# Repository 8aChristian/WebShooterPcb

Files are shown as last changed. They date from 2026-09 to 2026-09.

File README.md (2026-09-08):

# 🕸️ WebShooter — Wearable Actuation & High-Response Sensing PCB

<div align="center">



[]()
[]()


</div>

<p align="center">
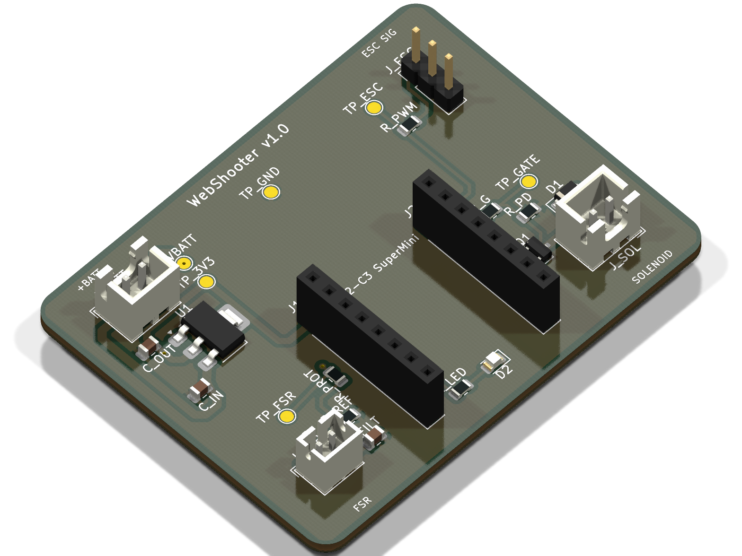
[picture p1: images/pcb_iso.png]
WebShooter 3D PCB Render Isometric View
  
</p>

---

## 1. 🎯 Objective

**WebShooter** is a compact, high-reliability wearable controller PCB designed for rapid biosignal/force acquisition, low-latency electronic valve actuation, and external brushless motor ESC control.

Built around the **ESP32-C3 SuperMini** (RISC-V 32-bit architecture), the system is engineered to withstand intense inductive transients and severe electromagnetic interference (EMI) from high-power loads while providing precision analog readings from a Force Sensing Resistor (FSR).

> [!NOTE]
> **Key Capabilities:**
> - **Fast Response Time:** Sub-millisecond analog force detection via hardware RC filtering.
> - **Inductive Load Immunity:** High-speed Schottky flyback suppression and isolated ground return loops.
> - **Modular Design:** Socketed MCU mounting for effortless replacement and maintenance.

---

## 2. 🏗️ System Architecture

```mermaid
graph LR
    subgraph Power_Stage ["Power and Regulation Stage"]
        BATT["Battery LiPo 2S (7.4V - 8.4V)"] -->|J_BATT| LDO["AMS1117-3.3 LDO"]
        LDO -->|"10uF In + 22uF Out"| V33["3.3V DC Clean Rail"]
    end

    subgraph MCU_Stage ["Control Unit ESP32-C3 SuperMini"]
        V33 --> MCU["ESP32-C3 (RISC-V @ 160MHz)"]
        MCU -->|GPIO8| LED["Status Indicator LED"]
    end

    subgraph Sensor_Stage ["Analog Force Sensing"]
        V33 --> FSR_DIV["10k Ohm Reference Divider"]
        FSR["FSR402 Sensor"] --> FSR_DIV
        FSR_DIV -->|"100nF LowPass + 1k Ohm Prot"| ADC["GPIO0 (ADC1_CH0)"]
    end

    subgraph Actuation_Stage ["Power Actuation and Motor Drive"]
        MCU -->|GPIO7 Logic Gate| DRV["AO3400A N-MOSFET (30V / 5.7A)"]
        BATT -->|7.4V Heavy Rail| SOL["Solenoid Valve (Inductive Load)"]
        DRV -->|"Drain + SS14 Flyback Diode"| SOL
        MCU -->|"GPIO6 PWM - 100 Ohm Damper"| ESC["External ESC (SpeedX2 1404 BLDC)"]
        BATT -.->|"Direct Battery Wiring"| ESC
    end
```

- **MCU:** ESP32-C3 SuperMini (RISC-V 32-bit single-core @ 160 MHz, 400 KB SRAM, 4 MB Flash, Wi-Fi + BLE 5).
- **Analog Front-End (AFE):** Precision voltage divider with a 100 nF ceramic low-pass filter ($f_c \approx 159\text{ Hz}$) and $1\text{ k}\Omega$ series current limiter.
- **Power Management & Drive:** AMS1117-3.3 LDO regulator with dual ceramic filtering; logic-level AO3400A N-MOSFET with SS14 Schottky flyback protection; isolated ESC PWM signaling.

---

## 3. 🔬 Component Selection & Design Decisions

| Subsystem | Component Selected | Engineering Rationale & Justification |
| :--- | :--- | :--- |
| **Microcontroller** | **ESP32-C3 SuperMini** | Ultra-compact footprint ($22.5 \times 18\text{ mm}$), native 12-bit ADC, hardware PWM timers, low power consumption, and integrated 2.4 GHz Wi-Fi/BLE for wireless telemetry. Mounted on **2.54 mm female headers** (`J1`, `J2`) to prevent module thermal stress during assembly and allow instant replacement. |
| **Solenoid Driver** | **AO3400A N-MOSFET** (SOT-23) | Ultra-low on-resistance ($R_{DS(on)} < 33\text{ m}\Omega$ @ $V_{GS} = 2.5\text{V}$), fully saturated with the ESP32's 3.3V logic. At $I = 0.8\text{A}$, power dissipation is negligible ($P_{cond} \approx 21.1\text{ mW}$), eliminating the need for bulky heatsinks. |
| **Flyback Protection** | **SS14 Schottky Diode** (SOD-123) | Placed directly in antiparallel across the solenoid terminals. Ultrafast reverse recovery ($t_{rr} < 10\text{ ns}$) and $0.5\text{V}$ forward drop clamp inductive voltage spikes ($V = -L \frac{di}{dt}$) to protect the MOSFET drain and ground plane from EMI bursts. |
| **Voltage Regulator** | **AMS1117-3.3** (SOT-223) | Handles 7.4V–8.4V LiPo 2S input with 1A current capacity. SOT-223 tab is tied to the output plane for optimal thermal dissipation. Paired with $10\,\mu\text{F}$ input and $22\,\mu\text{F}$ output ceramic X7R capacitors. |
| **Force Sensor AFE** | **FSR402 Divider + RC Filter** | Converts pressure ($0.2\text{ N} - 20\text{ N}$) into a clean $0.03\text{V} - 3.0\text{V}$ voltage curve. The hardware RC filter ($10\text{ k}\Omega \parallel 100\text{ nF}$) removes mechanical contact bounce and EMI from nearby motor switching. |
| **Motor & ESC Isolation** | **Signal-Only PWM Interface** | Heavy motor currents (up to 15A from the SpeedX2 1404 BLDC) are powered **directly from the battery pack wiring harness**. Only the PWM control line and reference ground pass through the PCB, preventing ground bounce and motor hash from corrupting the ADC. |

---

## 4. 📐 Schematic Overview

<div align="center">
  <a href="schematic/WebShooter_Schematic.pdf">
    WebShooter Complete Schematic Diagram
  </a>
  <p><em>Full vector PDF schematic is available in the <a href="schematic/WebShooter_Schematic.pdf"><code>/schematic</code></a> folder.</em></p>
</div>

> [!TIP]
> **Complete Schematic Documentation:**
> - 📄 **PDF Format:** [`schematic/WebShooter_Schematic.pdf`](schematic/WebShooter_Schematic.pdf)
> - 🎨 **Vector SVG:** [`schematic/WebShooter_Schematic.svg/`](schematic/WebShooter_Schematic.svg/)
> - 💻 **KiCad Source:** [`pcb/WebShooter.kicad_sch`](pcb/WebShooter.kicad_sch)

---

## 5. 🖨️ PCB Layout & Routing Strategy

<div align="center">

| Top Layer 2D Layout (F.Cu) | Bottom Layer 2D Layout (B.Cu) |
| :---: | :---: |
| Top Layer 2D PCB Layout | Bottom Layer 2D PCB Layout |

| 3D Render - Top Side | 3D Render - Bottom Side |
| :---: | :---: |
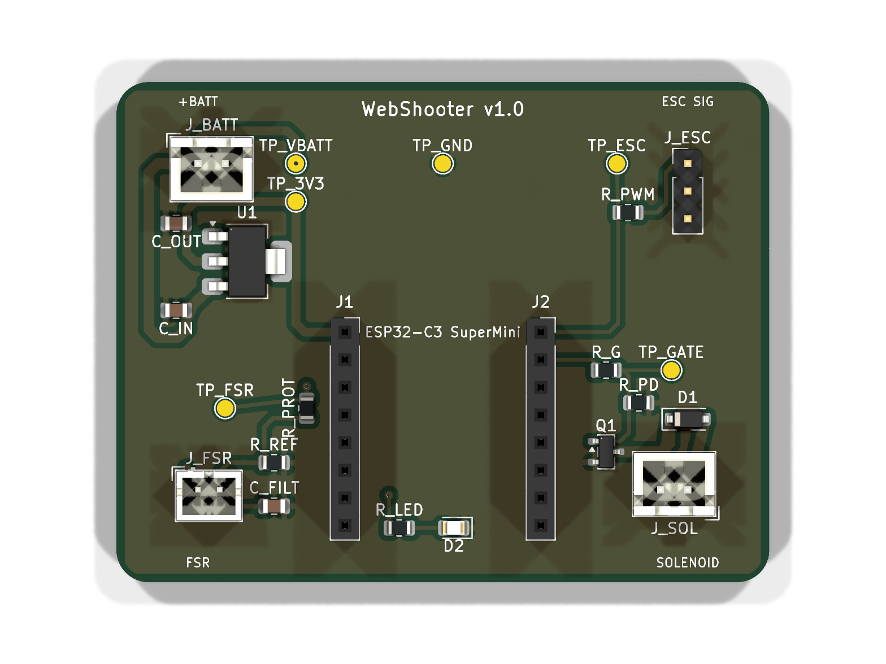
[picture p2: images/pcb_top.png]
Top Side 3D PCB Render
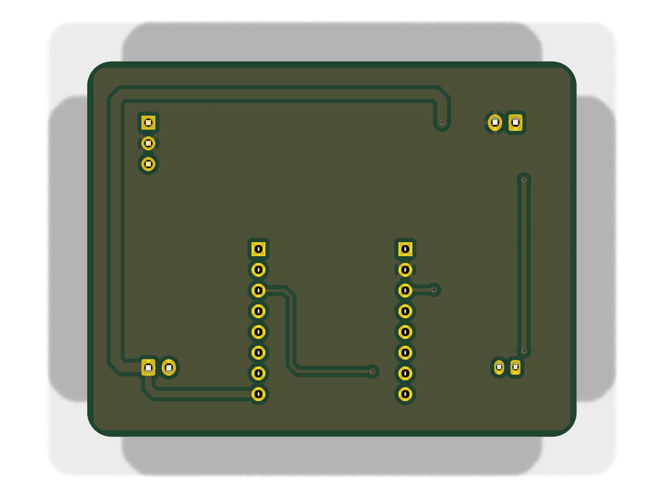
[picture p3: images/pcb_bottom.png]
Bottom Side 3D PCB Render
|  |  |

</div>

### 🛠️ Layer Stackup & Dimensions
- **Layer Count:** 2-Layer FR4 ($1.6\text{ mm}$ board thickness, $1\text{ oz} / 35\,\mu\text{m}$ copper weight).
- **Board Dimensions:** $38.0\text{ mm} \times 38.0\text{ mm}$ with $2.0\text{ mm}$ corner radius fillets (Ultra-compact wearable standard).
- **Mounting Hole Grid:** 4x M2 mounting holes on a $31.0 \times 31.0\text{ mm}$ pattern ($3.5\text{ mm}$ from board edges).

### 📐 Routing Guidelines & DFM Standards Applied
1. **Strict 45° Mitered Routing (Zero 90° Corners):**
   - All track bends utilize **45-degree chamfers** or smooth radii.
   - *Why:* Eliminates **acid traps** during chemical etching in fab, avoids acute impedance steps, and prevents solder mask delamination.
2. **Edge Pullback Clearance ($\ge 1.0\text{ mm}$):**
   - All copper tracks, vias, and copper pour zones maintain at least **$1.0\text{ mm}$ of clearance** from the `Edge_Cuts` perimeter.
   - *Why:* Prevents copper shearing, burrs, and shorts during CNC V-scoring and board routing.
3. **Trace Width Dimensioning (IPC-2152):**
   - **Power & Solenoid Traces:** $1.0\text{ mm} - 1.2\text{ mm}$ (Handles up to $3\text{A}$ continuous with $\Delta T < 10^\circ\text{C}$).
   - **3.3V Power Distribution:** $0.8\text{ mm}$.
   - **Digital PWM & Analog Signals:** $0.35\text{ mm} - 0.40\text{ mm}$.
4. **Dual Continuous Ground Planes:**
   - Both `F.Cu` and `B.Cu` feature unbroken GND copper zones connected through thermal reliefs (`ZONE_CONNECTION_THERMAL`) on all through-hole and SMD ground pins.

---

## 6. ✅ DRC & Quality Verification

Automated Design Rule Check (DRC) executed via `kicad-cli`:

```text
** KiCad 10 Design Rule Check Report **
Project: WebShooter.kicad_pcb
Date: 2026-08-20

[+] Status: PASSED
[+] Total DRC Violations: 0
[+] Unconnected Elements: 0
[+] Footprint Courtyard Overlaps: 0
[+] Solder Mask Bridges: 0
[+] Silk Over Exposure: 0
```

> [!IMPORTANT]
> The full verification report is saved in [`pcb/WebShooter-drc.rpt`](pcb/WebShooter-drc.rpt).

---

## 7. 🧊 3D Model & Mechanical Integration

<p align="center">
  3D Raytracing Render of WebShooter PCB
</p>

- **PCB 3D Model:** Ready-to-import STEP file:
  - 📁 [`3d-model/WebShooter.step`](3d-model/WebShooter.step)
- **Wearable Case / Enclosure (CAD):** Parametric wrist case model for 3D printing:
  - 📦 [`3d-model/WEBSHOOTERCASEFINAL.f3d`](3d-model/WEBSHOOTERCASEFINAL.f3d) (Autodesk Fusion 360 source archive)
- **Mechanical Mounting:** 4x M2 mounting holes on a $31.0 \times 31.0\text{ mm}$ square grid ($3.5\text{ mm}$ edge offset), designed to mate directly with the 3D-printed enclosure standoffs.

---

## 8. 🏭 Manufacturing & Assembly (JLCPCB / PCBWay Ready)

| Asset | Location / File | Purpose |
| :--- | :--- | :--- |
| **Gerber Files (ZIP)** | [`gerbers/WebShooter_Gerbers_JLCPCB.zip`](gerbers/WebShooter_Gerbers_JLCPCB.zip) | One-click drag-and-drop file for instant online quoting |
| **Individual Gerbers** | [`gerbers/`](gerbers/) | Standard RS-274X layers (`.gtl`, `.gbl`, `.gts`, `.gbs`, `.gto`, `.gm1`...) |
| **Drill File** | [`gerbers/WebShooter.drl`](gerbers/WebShooter.drl) | Excellon CNC drill specifications |
| **BOM (CSV)** | [`bom/WebShooter_BOM.csv`](bom/WebShooter_BOM.csv) | Component spreadsheet with LCSC Part Numbers |
| **BOM (Markdown)** | [`bom/WebShooter_BOM.md`](bom/WebShooter_BOM.md) | Formatted Bill of Materials table |
| **Case CAD (F3D)** | [`3d-model/WEBSHOOTERCASEFINAL.f3d`](3d-model/WEBSHOOTERCASEFINAL.f3d) | 3D-printable parametric enclosure design |

### 🚀 Production Parameters Recommended
- **Base Material:** FR-4 (Tg 130–140°C).
- **PCB Thickness:** 1.6 mm.
- **Copper Weight:** 1 oz ($35\,\mu\text{m}$).
- **Surface Finish:** HASL Lead-Free or ENIG (Electroless Nickel Immersion Gold).
- **Solder Mask:** Matte Black / Blue / Green.
- **Silkscreen:** High-contrast White.

---

## 📜 License

This project is licensed under the [MIT License](LICENSE) — Feel free to use, modify, and manufacture this board for open-source and commercial hardware projects.

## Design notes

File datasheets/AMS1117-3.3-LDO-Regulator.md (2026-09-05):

# AMS1117-3.3 Low Dropout (LDO) Voltage Regulator

## 📌 Resumen General
El **AMS1117-3.3** es un regulador de tensión lineal de bajo dropout capaz de suministrar hasta 1A de corriente de salida con una tensión estabilizada de 3.3V.

## ⚙️ Características Técnicas
- **Encapsulado**: SOT-223-3 (con lengüeta disipadora Tab conectada a $V_{OUT}$).
- **Voltaje de Entrada ($V_{IN}$)**: Hasta 15V (Operación a 7.4V - 8.4V LiPo 2S).
- **Voltaje de Salida ($V_{OUT}$)**: $3.3	ext{V} \pm 1.5\%$.
- **Dropout Voltage**: 1.1V a 1A.
- **Corriente de Salida Máxima**: 1.0A (con protección interna contra sobrecorriente y sobretemperatura).

## 🔌 Requisitos de Filtrado y Desacoplo (DFM)
- **Capacitor de Entrada ($C_{IN}$)**: $10\,\mu	ext{F}$ cerámico X7R (0805) colocado a $< 2	ext{ mm}$ del Pin 3.
- **Capacitor de Salida ($C_{OUT}$)**: $22\,\mu	ext{F}$ cerámico X7R (0805) para garantizar estabilidad del bucle de control.

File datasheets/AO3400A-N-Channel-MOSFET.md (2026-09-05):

# AO3400A N-Channel Enhancement Mode MOSFET

## 📌 Resumen General
El **AO3400A** de Alpha & Omega Semiconductor es un MOSFET de canal N de nivel lógico (*Logic-Level*) diseñado para conmutación de alta velocidad y baja resistencia en conducción.

## ⚙️ Características Técnicas
- **Encapsulado**: SOT-23 (3 pines).
- **Voltaje Drenador-Fuente ($V_{DS}$)**: 30V máx.
- **Voltaje Compuerta-Fuente ($V_{GS}$)**: $\pm 12	ext{V}$ máx.
- **Corriente Continua de Drenador ($I_D$)**: 5.7A a $25^\circ	ext{C}$.
- **Resistencia en Conducción ($R_{DS(on)}$)**:
  - $< 28	ext{ m}\Omega$ a $V_{GS} = 4.5	ext{V}$
  - $< 33	ext{ m}\Omega$ a $V_{GS} = 2.5	ext{V}$ (100% compatible con 3.3V lógico del ESP32).
- **Disipación de Potencia en WebShooter**:
  - Para solenoide a 7.4V con $I = 0.8	ext{A}$:
  - $P = I^2 	imes R_{DS(on)} = (0.8)^2 	imes 0.033 pprox 21.1	ext{ mW}$ (Elevación térmica $< 3^\circ	ext{C}$).

## 🔌 Conexión en Circuito
- **Pin 1 (Gate)**: Conectado a GPIO7 mediante $R_G = 100\,\Omega$ y pull-down $R_{PD} = 10	ext{ k}\Omega$.
- **Pin 2 (Source)**: Conectado al plano de masa común (GND).
- **Pin 3 (Drain)**: Conectado al terminal negativo de la válvula solenoide ($J_{SOL}$ Pin 2).

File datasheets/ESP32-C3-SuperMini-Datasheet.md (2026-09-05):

# ESP32-C3 SuperMini Microcontroller Module

## 📌 Resumen General
El **ESP32-C3 SuperMini** es una placa de desarrollo compacta basada en el chip **Espressif ESP32-C3FN4** con arquitectura RISC-V de 32 bits y un solo núcleo.

## ⚙️ Especificaciones Principales
- **Procesador**: RISC-V 32-bit single-core @ hasta 160 MHz.
- **Memoria**: 400 KB SRAM, 384 KB ROM, 4 MB Flash integrada.
- **Conectividad**: Wi-Fi 802.11 b/g/n (2.4 GHz) + Bluetooth 5 (LE).
- **Voltaje de Operación (Lógico)**: 3.3V DC.
- **Voltaje de Entrada (Pin 5V/VCC)**: 3.3V a 6.0V.
- **Consumo en Deep Sleep**: ~5 µA.

## 🔌 Pinout y Mapeo en WebShooter
| Pin Físico | Pin ESP32 | Función en WebShooter | Descripción |
| :--- | :--- | :--- | :--- |
| **J1 Pin 1** | 3.3V | Entrada de Alimentación | Riel regulado 3.3V desde AMS1117 |
| **J1 Pin 2** | GND | Tierra del Sistema | Conexión al plano de masa común |
| **J1 Pin 3** | GPIO0 (ADC1_CH0) | Entrada Analógica FSR | Lectura de fuerza con divisor resistivo |
| **J2 Pin 1** | GPIO6 | Salida PWM ESC | Señal de control para motor BLDC (50-400Hz) |
| **J2 Pin 2** | GPIO7 | Disparo Solenoide | Compuerta lógica del MOSFET AO3400A |
| **J2 Pin 3** | GPIO8 | LED de Estado | Indicador LED en placa con R limitadora |

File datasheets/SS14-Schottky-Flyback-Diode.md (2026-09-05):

# SS14 Surface Mount Schottky Barrier Rectifier

## 📌 Resumen General
El **SS14** es un diodo rectificador Schottky de alta velocidad y baja caída de tensión directa, ideal para protección contra picos inductivos (*flyback/freewheeling*).

## ⚙️ Características Técnicas
- **Encapsulado**: SOD-123 / SMA.
- **Voltaje Inverso Repetitivo ($V_{RRM}$)**: 40V.
- **Corriente Media Directa ($I_{F(AV)}$)**: 1.0A.
- **Caída de Tensión Directa ($V_F$)**: $pprox 0.50	ext{V}$ a 1A.
- **Tiempo de Recuperación Inversa ($t_{rr}$)**: Ultrarrápido (< 10 ns).

## 🔌 Función en WebShooter
- Conectado en antiparalelo directo a través de los terminales de la válvula solenoide ($J_{SOL}$).
- Suprime la fuerza contraelectromotriz ($V = -L 
rac{di}{dt}$) al abrir el MOSFET $Q1$, protegiendo la unión de drenador y evitando perturbaciones electromagnéticas en el microcontrolador.

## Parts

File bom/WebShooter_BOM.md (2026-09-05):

# Lista de Materiales (Bill of Materials - BOM) - WebShooter v1.0

| Item | Designador | Cant | Valor | Encapsulado | Descripción | Fabricante / Nro Parte | Código LCSC |
| :--- | :--- | :--- | :--- | :--- | :--- | :--- | :--- |
| 1 | `J1, J2` | 2 | **PinSocket_1x08_P2.54mm** | `Connector_PinSocket_2.54mm:PinSocket_1x08_P2.54mm_Vertical` | Zócalo hembra 1x8 2.54mm para ESP32-C3 SuperMini | Generic | `C224522` |
| 2 | `J_BATT` | 1 | **JST_XH_B2B-XH-A** | `Connector_JST:JST_XH_B2B-XH-A_1x02_P2.50mm_Vertical` | Conector Batería LiPo 2S (7.4V) | JST / B2B-XH-A | `C157929` |
| 3 | `J_SOL` | 1 | **JST_XH_B2B-XH-A** | `Connector_JST:JST_XH_B2B-XH-A_1x02_P2.50mm_Vertical` | Conector Válvula Solenoide (7.4V) | JST / B2B-XH-A | `C157929` |
| 4 | `J_FSR` | 1 | **JST_PH_B2B-PH-K** | `Connector_JST:JST_PH_B2B-PH-K_1x02_P2.00mm_Vertical` | Conector Sensor de Presión FSR402 | JST / B2B-PH-K | `C131337` |
| 5 | `J_ESC` | 1 | **PinHeader_1x03_P2.54mm** | `Connector_PinHeader_2.54mm:PinHeader_1x03_P2.54mm_Vertical` | Conector de señal PWM y GND para ESC | Generic | `C49257` |
| 6 | `U1` | 1 | **AMS1117-3.3** | `Package_TO_SOT_SMD:SOT-223-3_TabPin2` | Regulador LDO 3.3V 1A | Advanced Monolithic Systems / AMS1117-3.3 | `C6186` |
| 7 | `Q1` | 1 | **AO3400A** | `Package_TO_SOT_SMD:SOT-23` | MOSFET N-Channel 30V 5.7A Logic Level | Alpha & Omega Semi / AO3400A | `C20917` |
| 8 | `D1` | 1 | **SS14** | `Diode_SMD:D_SOD-123` | Diodo Schottky Flyback 40V 1A | MDD / SS14 | `C2480` |
| 9 | `D2` | 1 | **LED_0805_Blue** | `LED_SMD:LED_0805_2012Metric` | LED de Estado SMD 0805 | Everlight / 19-217/BHC-AP1Q2/3T | `C2290` |
| 10 | `C_IN` | 1 | **10uF 25V X7R** | `Capacitor_SMD:C_0805_2012Metric` | Condensador Cerámico SMD 0805 | Samsung / CL21B106KOQNNNE | `C15850` |
| 11 | `C_OUT` | 1 | **22uF 10V X7R** | `Capacitor_SMD:C_0805_2012Metric` | Condensador Cerámico SMD 0805 | Samsung / CL21B226MPQNNNE | `C45783` |
| 12 | `C_FILT` | 1 | **100nF 50V X7R** | `Capacitor_SMD:C_0805_2012Metric` | Condensador Filtro FSR SMD 0805 | Yageo / CC0805KRX7R9BB104 | `C49678` |
| 13 | `R_REF, R_PD` | 2 | **10k 1%** | `Resistor_SMD:R_0805_2012Metric` | Resistencias SMD 0805 (FSR ref & Gate PD) | Uniroyal / 0805W8F1002T5E | `C17414` |
| 14 | `R_PROT, R_LED` | 2 | **1k 1%** | `Resistor_SMD:R_0805_2012Metric` | Resistencias SMD 0805 (ADC prot & LED) | Uniroyal / 0805W8F1001T5E | `C17513` |
| 15 | `R_G, R_PWM` | 2 | **100 1%** | `Resistor_SMD:R_0805_2012Metric` | Resistencias SMD 0805 (Gate & PWM damp) | Uniroyal / 0805W8F1000T5E | `C17407` |
| 16 | `TP_VBATT..TP_GATE` | 6 | **TestPoint_Pad_D1.5mm** | `TestPoint:TestPoint_Pad_D1.5mm` | Puntos de prueba SMD para depuración | Keystone / Generic | `N/A` |

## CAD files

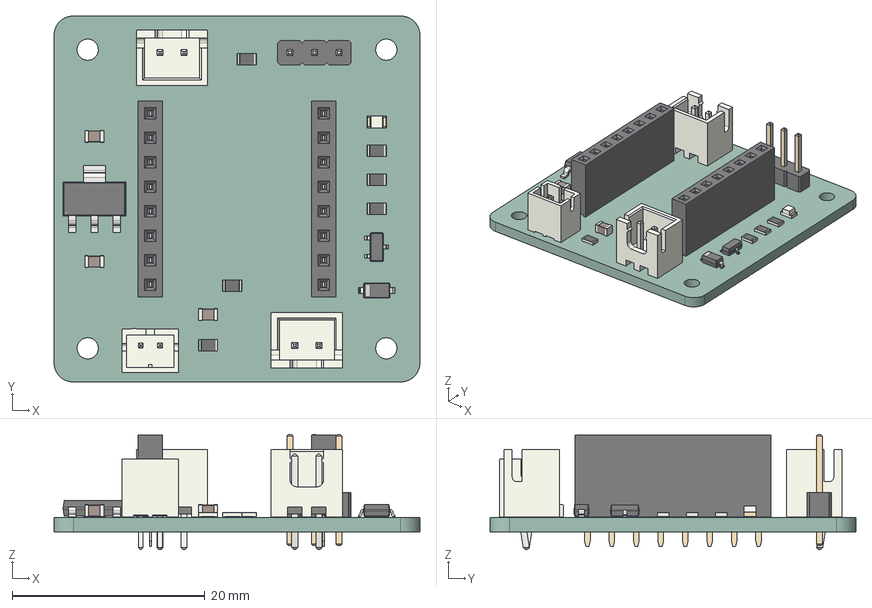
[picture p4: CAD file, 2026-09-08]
3d-model/WebShooter.step
38.0 x 38.0 x 11.9 mm
D_SOD-123
C_0805_2012Metric x 3
JST_PH_B2B-PH-K_1x02_P2.00mm_Vertical
R_0805_2012Metric x 6
LED_0805_2012Metric
PinSocket_1x08_P2.54mm_Vertical x 2
SOT-23
SOT-223
JST_XH_B2B-XH-A_1x02_P2.50mm_Vertical x 2
PinHeader_1x03_P2.54mm_Vertical
WebShooter_PCB

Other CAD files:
3d-model/WEBSHOOTERCASEFINAL.f3d
3d-model/WebShooter_Case.blend

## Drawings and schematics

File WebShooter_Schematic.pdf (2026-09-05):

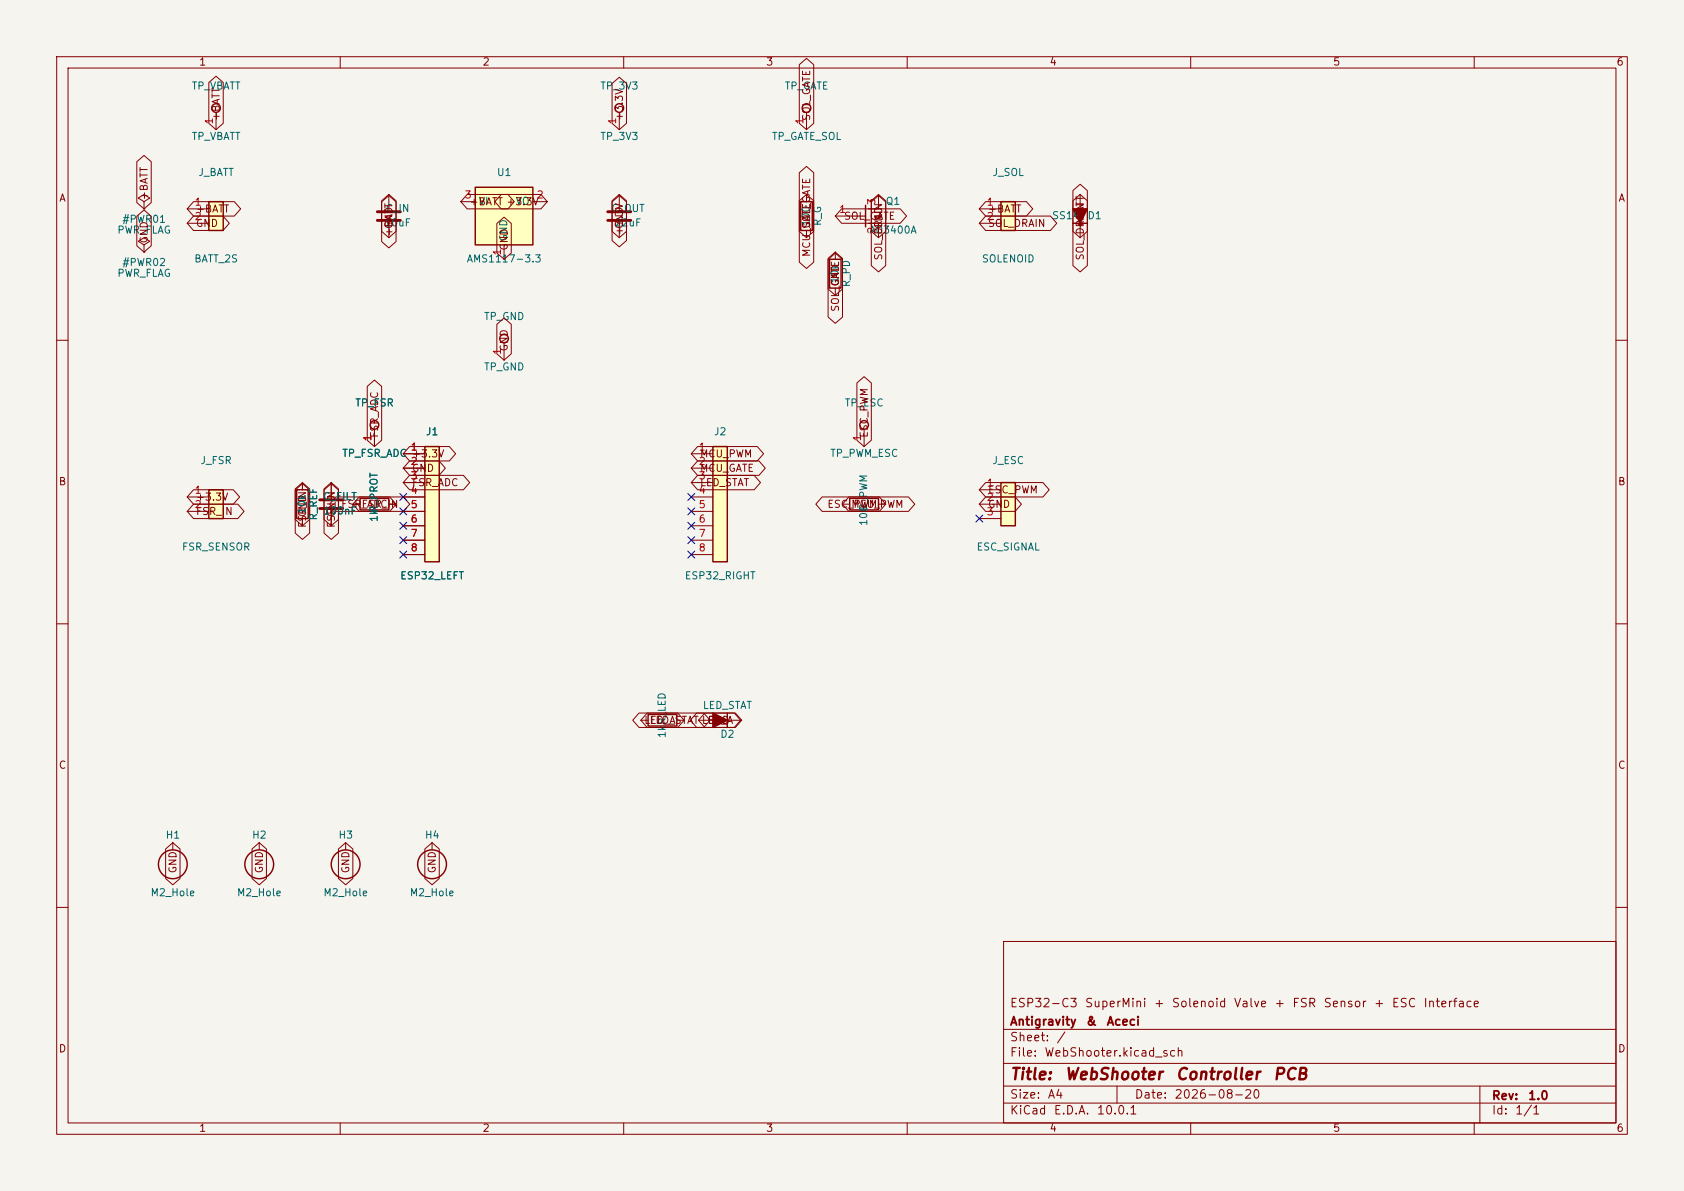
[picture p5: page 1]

ESP32-C3 SuperMini + Solenoid Valve + FSR Sensor + ESC Interface
Antigravity & Aceci
Sheet: /
File: WebShooter.kicad_sch
Title: WebShooter Controller PCB

Size: A4 | Rev: 1.0
KiCad E.D.A. 10.0.1 | Id: 1/1

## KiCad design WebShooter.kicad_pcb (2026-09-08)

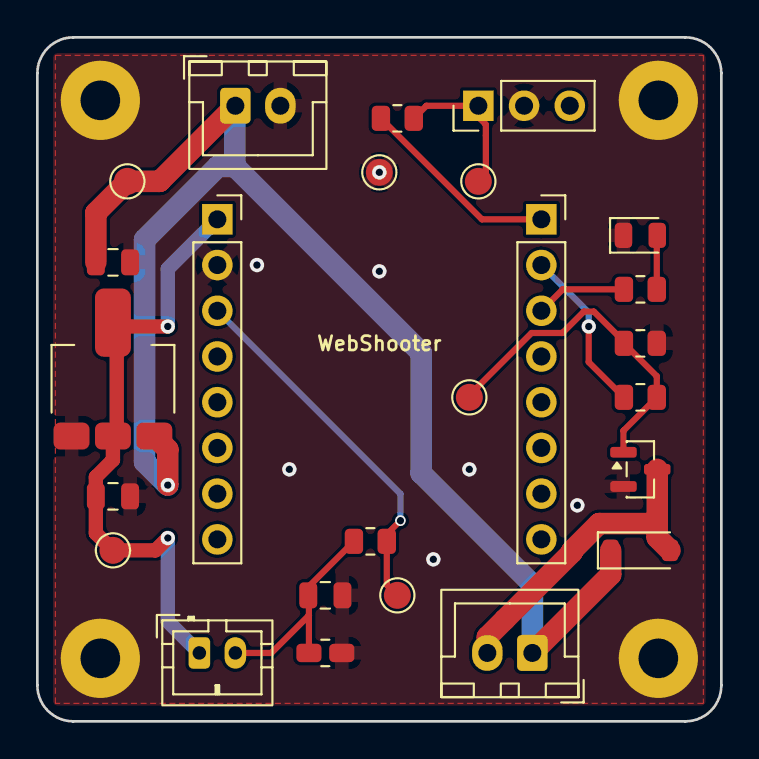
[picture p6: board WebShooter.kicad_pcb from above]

Board: 2 copper layers, 38.0 x 38.0 mm, 29 parts (0 on the bottom side), 12 nets.

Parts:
C_FILT: 100nF; C_0805_2012Metric
C_IN: 10uF; C_0805_2012Metric
C_OUT: 22uF; C_0805_2012Metric
D1: SS14; D_SOD-123
D2: LED_STAT; LED_0805_2012Metric
H1, H2, H3, H4: MountingHole_2.2mm_M2_Pad
J1: ESP32_LEFT; PinSocket_1x08_P2.54mm_Vertical
J2: ESP32_RIGHT; PinSocket_1x08_P2.54mm_Vertical
J_BATT: BATT_2S; JST_XH_B2B-XH-A_1x02_P2.50mm_Vertical
J_ESC: ESC_SIG; PinHeader_1x03_P2.54mm_Vertical
J_FSR: FSR_SENSOR; JST_PH_B2B-PH-K_1x02_P2.00mm_Vertical
J_SOL: SOLENOID; JST_XH_B2B-XH-A_1x02_P2.50mm_Vertical
Q1: AO3400A; SOT-23
R_G: 100; R_0805_2012Metric
R_LED: 1k; R_0805_2012Metric
R_PD: 10k; R_0805_2012Metric
R_PROT: 1k; R_0805_2012Metric
R_PWM: 100; R_0805_2012Metric
R_REF: 10k; R_0805_2012Metric
TP_3V3: TP_3V3; TestPoint_Pad_D1.5mm
TP_ESC: TP_ESC; TestPoint_Pad_D1.5mm
TP_FSR: TP_FSR; TestPoint_Pad_D1.5mm
TP_GATE: TP_GATE; TestPoint_Pad_D1.5mm
TP_GND: TP_GND; TestPoint_Pad_D1.5mm
TP_VBATT: TP_VBATT; TestPoint_Pad_D1.5mm
U1: AMS1117-3.3; SOT-223-3_TabPin2

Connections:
+3.3V: C_OUT.1, J1.1, J_FSR.1, TP_3V3.1, U1.2
+BATT: C_IN.1, D1.1, J_BATT.1, J_SOL.1, TP_VBATT.1, U1.3
ESC_PWM: J_ESC.1, R_PWM.2, TP_ESC.1
FSR_ADC: J1.3, R_PROT.2, TP_FSR.1
FSR_IN: C_FILT.1, J_FSR.2, R_PROT.1, R_REF.1
GND: C_FILT.2, C_IN.2, C_OUT.2, D2.1, H1.1, H2.1, H3.1, H4.1, J1.2, J_BATT.2, J_ESC.2, Q1.2, R_PD.2, R_REF.2, TP_GND.1, U1.1
LED_A: D2.2, R_LED.2
LED_STAT: J2.3, R_LED.1
MCU_GATE: J2.2, R_G.1
MCU_PWM: J2.1, R_PWM.1
SOL_DRAIN: D1.2, J_SOL.2, Q1.3
SOL_GATE: Q1.1, R_G.2, R_PD.1, TP_GATE.1

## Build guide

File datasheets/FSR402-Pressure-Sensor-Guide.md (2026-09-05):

# Interlink Electronics FSR 402 Force Sensing Resistor

## 📌 Resumen General
El **FSR 402** es un sensor de resistencia variable por fuerza que disminuye su resistencia óhmica cuando se aplica presión mecánica sobre su área activa circular de 12.7 mm.

## ⚙️ Características Técnicas
- **Rango de Fuerza**: 0.2 N a 20 N (20 g a 2 kg).
- **Resistencia en Reposo (Sin Fuerza)**: $> 10	ext{ M}\Omega$.
- **Resistencia a Presión Moderada**: $pprox 10	ext{ k}\Omega$.
- **Resistencia a Presión Máxima**: $pprox 1	ext{ k}\Omega - 200\,\Omega$.

## 🔌 Circuito Divisor de Tensión y Filtrado
- **Topología**: $V_{ADC} = 3.3	ext{V} 	imes 
rac{R_{REF}}{R_{FSR} + R_{REF}}$ con $R_{REF} = 10	ext{ k}\Omega$.
- **Filtro Pasabajos**: $C_{FILT} = 100	ext{ nF}$ en paralelo con $R_{REF}$ ($f_c = 
rac{1}{2\pi R_{REF} C_{FILT}} pprox 159	ext{ Hz}$), eliminando rebotes y ruido de alta frecuencia.
- **Protección**: $R_{PROT} = 1	ext{ k}\Omega$ en serie antes del pin `GPIO0` del ESP32-C3 para limitar transitorios de corriente.

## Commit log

2026-09-05 feat: WebShooter Wearable PCB v1.0 (KiCad 10) - 0 DRC, 0 ERC, DFM/DFA ready
    [WebShooter-B_Courtyard.gbr, WebShooter-B_Cu.gbl, WebShooter-B_Fab.gbr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]
2026-09-08 feat: Redesign ultra-compact 38x38mm PCB, 0 DRC violations, 45deg routing & add 3D case CAD
    [WEBSHOOTERCASEFINAL.f3d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]

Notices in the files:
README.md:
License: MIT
